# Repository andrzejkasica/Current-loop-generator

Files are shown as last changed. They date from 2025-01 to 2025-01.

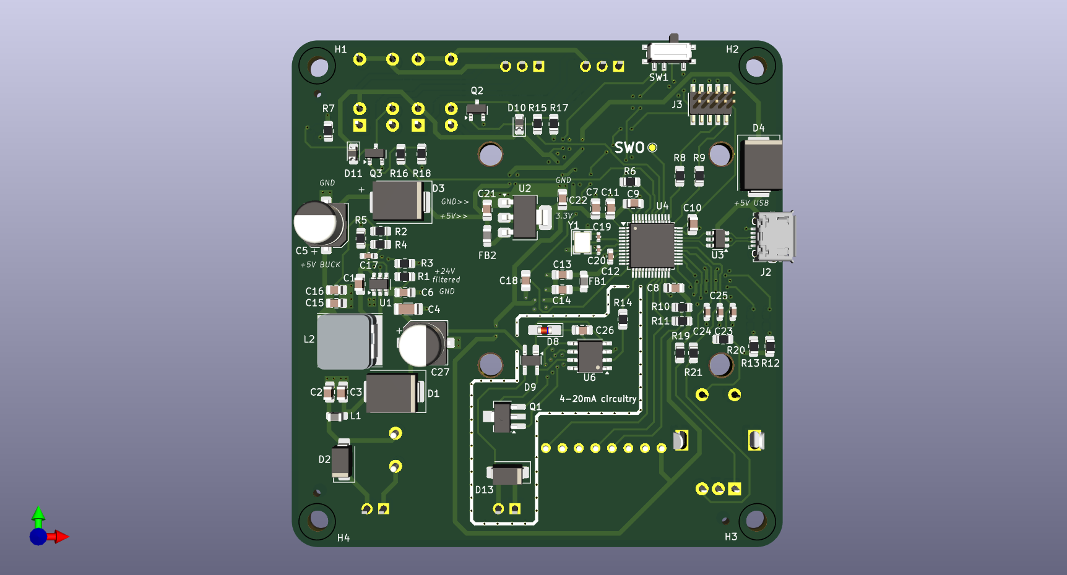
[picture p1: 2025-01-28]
Current_loop_gen-back.png

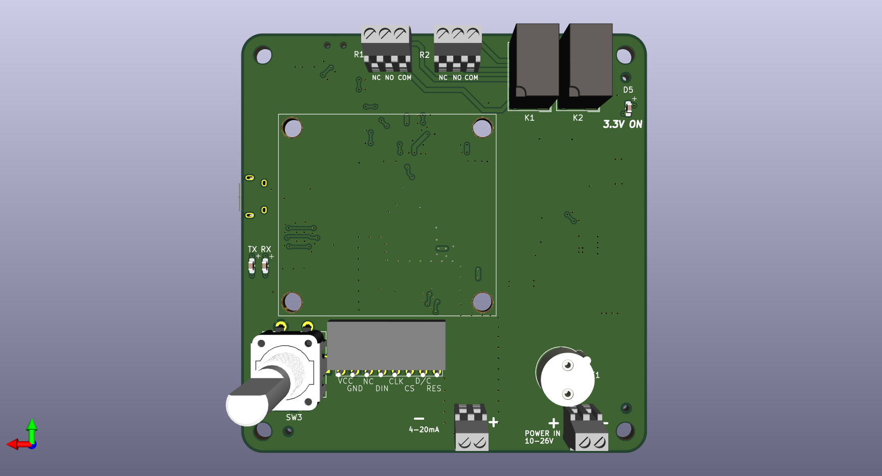
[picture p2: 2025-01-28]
Current_loop_gen-front.png

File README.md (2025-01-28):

# Current-loop-generator
Hardware project of 2-wire current loop generator with additonal 2 relays controlled by STM32L433CCT6 with OLED display and incremental encoder.
Powered with external 24V power supply, projects uses buck converter for +5V line and LDO for +3V3

PCB front: 
Current_loop_gen-front

Back of the PCB:
Current_loop_gen-back

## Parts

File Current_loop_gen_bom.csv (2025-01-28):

Reference | Value | Datasheet | Footprint | Qty | DNP | JLCPCB Part #
C12,C23,C24,C25 | 10n | ~ | -- różne wartości -- | 4 |  | C57112
C1,C2,C3,C6,C8,C9,C10,C11,C18,C26 | 100n | ~ | Capacitor_SMD:C_0805_2012Metric_Pad1.18x1.45mm_HandSolder | 10 |  | C49678
C15,C16,C21,C22 | 22u | ~ | Capacitor_SMD:C_0805_2012Metric_Pad1.18x1.45mm_HandSolder | 4 |  | C45783
C19,C20 | 10p | ~ | Capacitor_SMD:C_0402_1005Metric | 2 |  | C32949
C13,C14 | 1u | ~ | Capacitor_SMD:C_0805_2012Metric_Pad1.18x1.45mm_HandSolder | 2 |  | C28323
R4 | 100k | ~ | Resistor_SMD:R_0805_2012Metric_Pad1.20x1.40mm_HandSolder | 1 |  | C25741
R14 | 15k | ~ | Resistor_SMD:R_0805_2012Metric_Pad1.20x1.40mm_HandSolder | 1 |  | C17475
R17,R18 | 150k | ~ | Resistor_SMD:R_0805_2012Metric_Pad1.20x1.40mm_HandSolder | 2 |  | C17470
R19,R20,R21 | 10K | ~ | Resistor_SMD:R_0805_2012Metric_Pad1.20x1.40mm_HandSolder | 3 |  | C17414
R6 | 10k | ~ | Resistor_SMD:R_0805_2012Metric_Pad1.20x1.40mm_HandSolder | 1 |  | C17414
R8,R9 | 100 | ~ | Resistor_SMD:R_0805_2012Metric_Pad1.20x1.40mm_HandSolder | 2 |  | C17408
Y1 | 16MHz | ~ | Crystal:Crystal_SMD_3225-4Pin_3.2x2.5mm | 1 |  | C13738
U2 | AMS1117-3.3 | http://www.advanced-monolithic.com/pdf/ds1117.pdf | Package_TO_SOT_SMD:SOT-223-3_TabPin2 | 1 |  | C6186
FB1,L1 | 120R | ~ | Inductor_SMD:L_0805_2012Metric_Pad1.05x1.20mm_HandSolder | 2 |  | C5671
R7,R10,R11,R12,R13,R15,R16 | 1k5 | ~ | Resistor_SMD:R_0805_2012Metric_Pad1.20x1.40mm_HandSolder | 7 |  | C4310
C17 | 75p | ~ | Capacitor_SMD:C_0603_1608Metric_Pad1.08x0.95mm_HandSolder | 1 |  | C1671
FB2 | 100 @ 100MHz | ~ | Inductor_SMD:L_0805_2012Metric_Pad1.05x1.20mm_HandSolder | 1 |  | C1015

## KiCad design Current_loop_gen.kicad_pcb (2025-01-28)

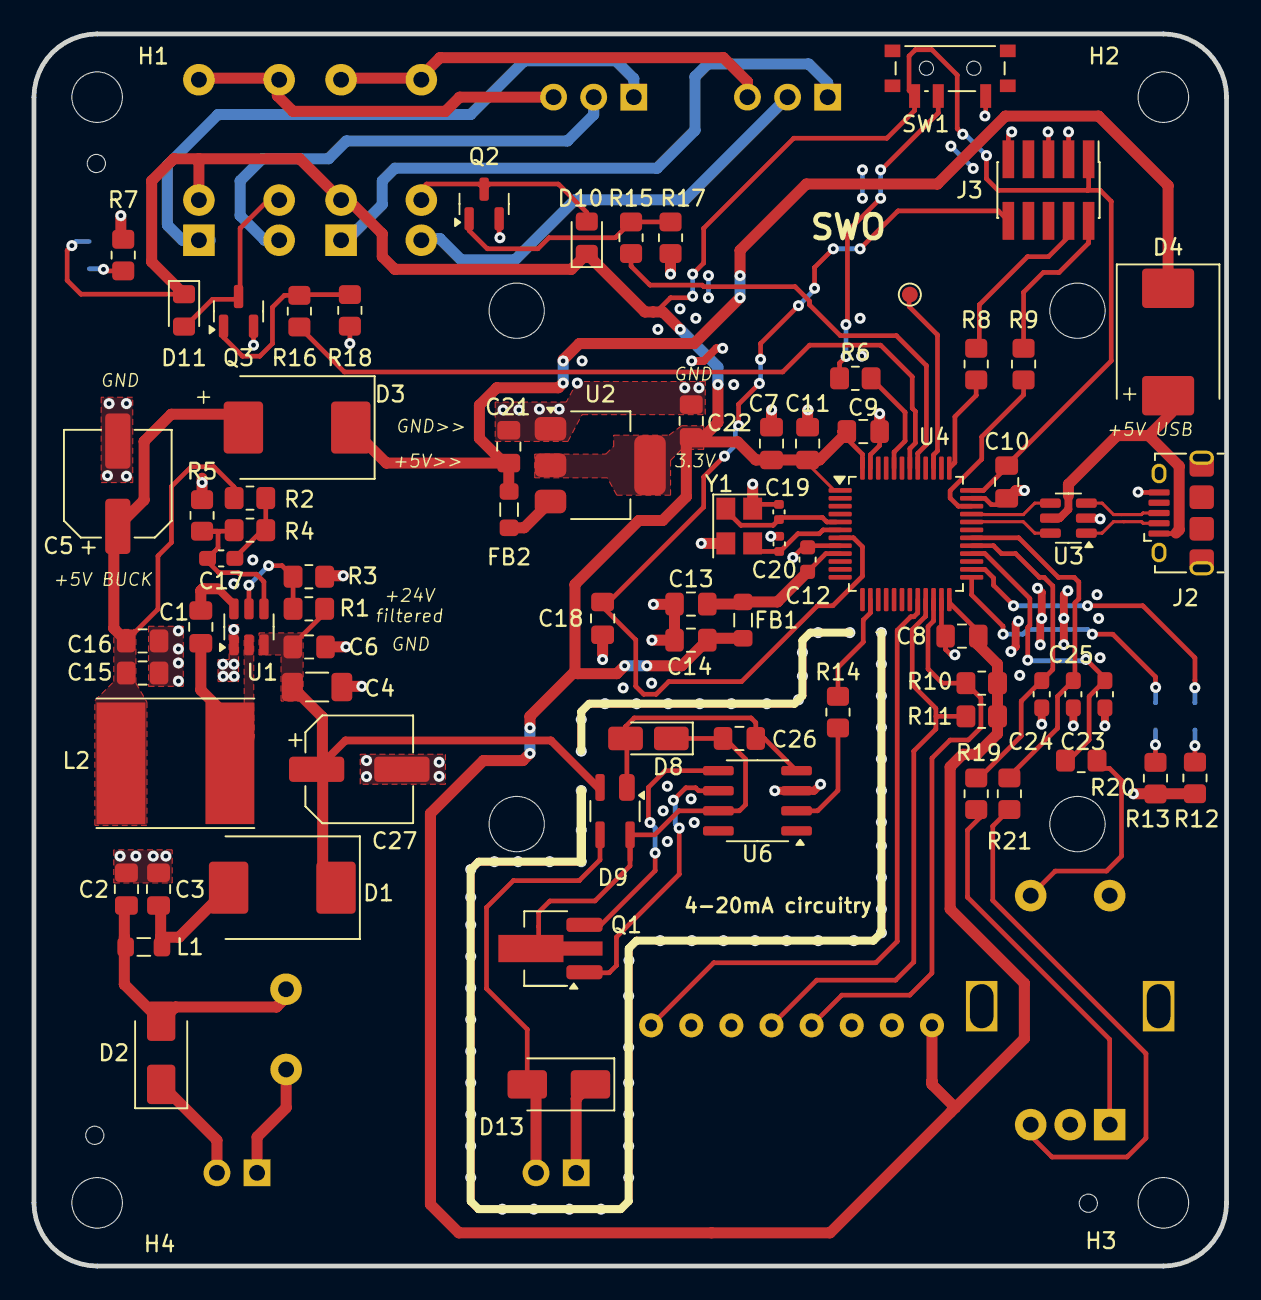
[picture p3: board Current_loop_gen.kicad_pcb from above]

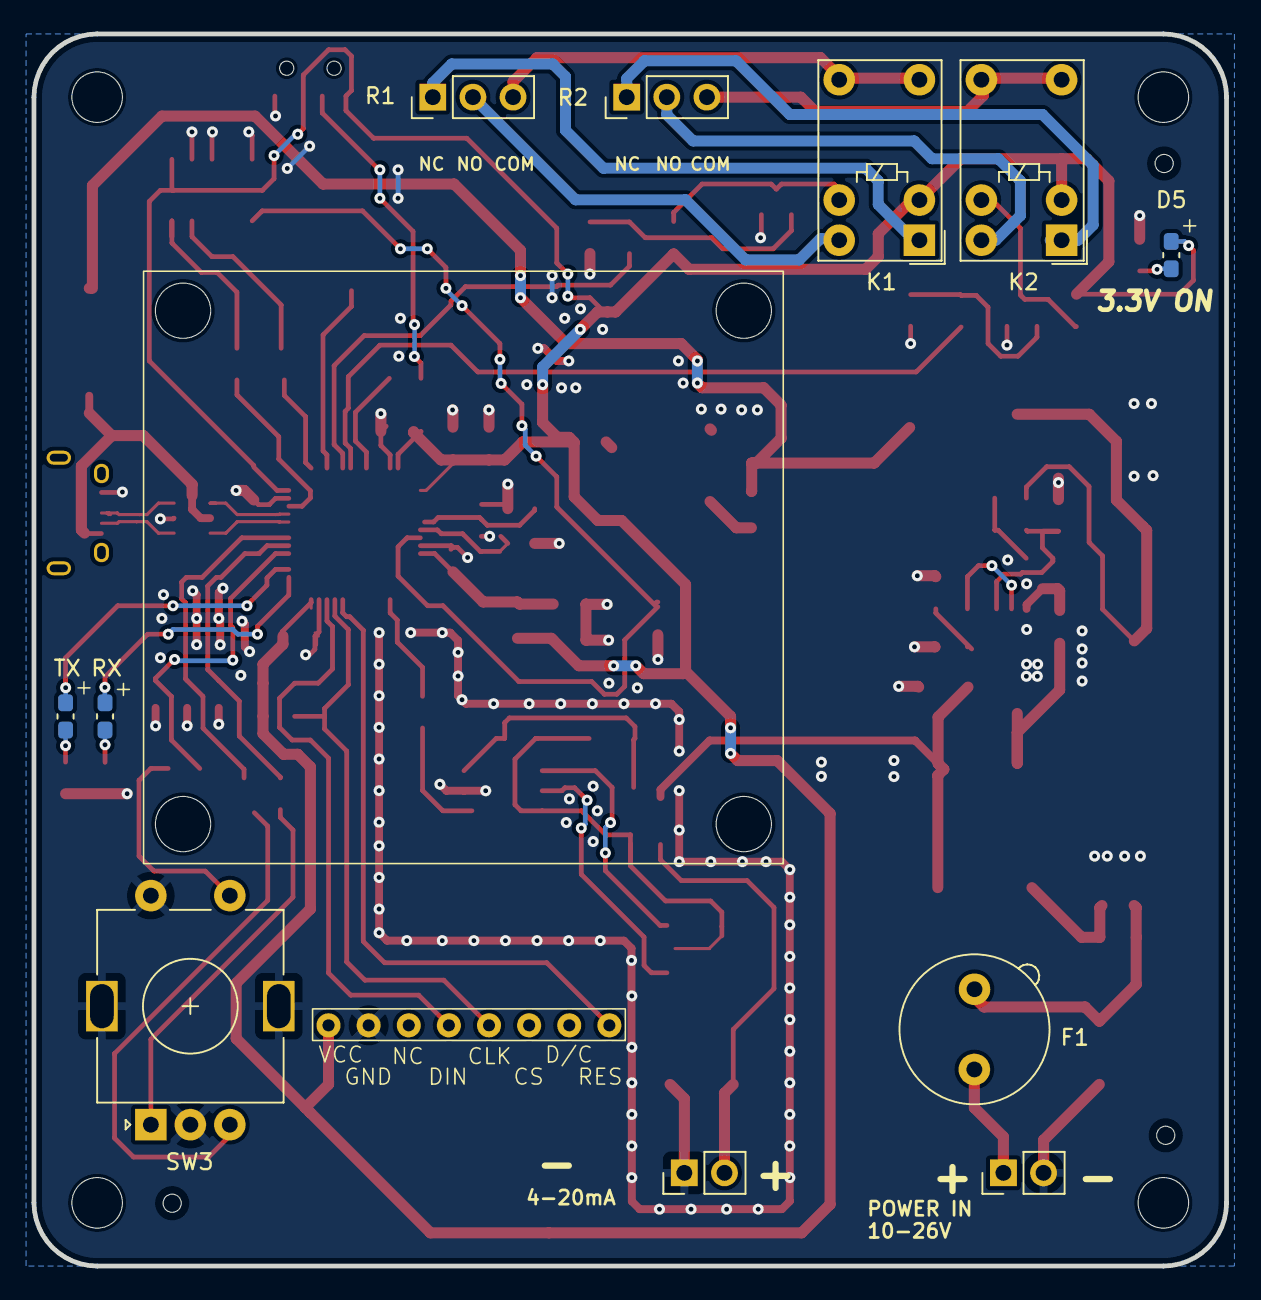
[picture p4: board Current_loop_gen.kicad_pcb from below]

Board: 2 copper layers, 75.5 x 78.0 mm, 90 parts (12 on the bottom side), 63 nets.

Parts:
C1, C2, C3, C6, C8, C9, C10, C11, C18, C26: 100n; C_0805_2012Metric_Pad1.18x1.45mm_HandSolder
C4: 22u; C_1206_3216Metric_Pad1.33x1.80mm_HandSolder
C5, C27: 47u; CP_Elec_6.3x5.8
C7: 10u; C_0805_2012Metric_Pad1.18x1.45mm_HandSolder
C12: 10n; C_0603_1608Metric
C13, C14: 1u; C_0805_2012Metric_Pad1.18x1.45mm_HandSolder
C15, C16, C21, C22: 22u; C_0805_2012Metric_Pad1.18x1.45mm_HandSolder
C17: 75p; C_0603_1608Metric_Pad1.08x0.95mm_HandSolder
C19, C20: 10p; C_0402_1005Metric
C23, C24, C25: 10n; C_0603_1608Metric_Pad1.08x0.95mm_HandSolder
D1: B340; D_SMC
D2, D13: SMAJ30CA; D_SMA
D3, D4: SX33L_R1; D_SMC
D5: RED; C_0603_1608Metric_Pad1.08x0.95mm_HandSolder
D6: BLUE; C_0603_1608Metric_Pad1.08x0.95mm_HandSolder
D7: GREEN; C_0603_1608Metric_Pad1.08x0.95mm_HandSolder
D8: 1N47xxA; D_MicroMELF_Handsoldering
D9: BAS4002ARPPE6327; SOT-143_Handsoldering
D10, D11: 1N4148; D_0805_2012Metric_Pad1.15x1.40mm_HandSolder
F1: Fuse_Small; Fuseholder_TR5_Littelfuse_No560_No460
FB1: 120R; L_0805_2012Metric_Pad1.05x1.20mm_HandSolder
FB2: 100 @ 100MHz; L_0805_2012Metric_Pad1.05x1.20mm_HandSolder
H1, H2, H3, H4: MountingHole; MountingHole_3.2mm_M3_DIN965
J1: Power 24V; PinHeader_1x02_P2.54mm_Vertical
J2: USB_B_Micro; USB_Micro-B_Amphenol_10118194-0001LF_Horizontal
J3: SWD Debug; PinHeader_2x05_P1.27mm_Vertical_SMD
J4: Current loop out; PinHeader_1x02_P2.54mm_Vertical
J5, J6: Conn_01x03; PinHeader_1x03_P2.54mm_Vertical
K1, K2: G5V-1; Relay_SPDT_Omron_G5V-1
L1: 120R; L_0805_2012Metric_Pad1.05x1.20mm_HandSolder
L2: 10u; L_Taiyo-Yuden_NR-80xx_HandSoldering
Q1: FCE690; SOT-89-3_Handsoldering
Q2, Q3: DMN65D8L-7; SOT-23
R1: 511k; R_0805_2012Metric_Pad1.20x1.40mm_HandSolder
R2: 49k9; R_0805_2012Metric_Pad1.20x1.40mm_HandSolder
R3: 105k; R_0805_2012Metric_Pad1.20x1.40mm_HandSolder
R4: 100k; R_0805_2012Metric_Pad1.20x1.40mm_HandSolder
R5: 13k3; R_0805_2012Metric_Pad1.20x1.40mm_HandSolder
R6: 10k; R_0805_2012Metric_Pad1.20x1.40mm_HandSolder
R7, R10, R11, R12, R13, R15, R16: 1k5; R_0805_2012Metric_Pad1.20x1.40mm_HandSolder
R8, R9: 100; R_0805_2012Metric_Pad1.20x1.40mm_HandSolder
R14: 15k; R_0805_2012Metric_Pad1.20x1.40mm_HandSolder
R17, R18: 150k; R_0805_2012Metric_Pad1.20x1.40mm_HandSolder
R19, R20, R21: 10K; R_0805_2012Metric_Pad1.20x1.40mm_HandSolder
SW1: SW_SPDT; SW_SPDT_PCM12
SW3: RotaryEncoder_Switch_MP; RotaryEncoder_Alps_EC11E-Switch_Vertical_H20mm
TP1: TestPoint; TestPoint_Pad_D1.0mm
U1: TPS54302; SOT-23-6
U2: AMS1117-3.3; SOT-223-3_TabPin2
U3: USBLC6-2SC6; SOT-23-6
U4: STM32L433CCTx; LQFP-48_7x7mm_P0.5mm
U5: WSH-10451; wsh-10451
U6: XTR116U; SOIC-8_3.9x4.9mm_P1.27mm
Y1: 16MHz; Crystal_SMD_3225-4Pin_3.2x2.5mm

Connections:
+3.3V: C7.1, C8.1, C9.1, C10.1, C11.1, C14.1, C22.1, D5.2 (A), D10.1 (K), D11.1 (K), FB1.2, J3.1, K1.2, K2.2, R10.1, R11.1, SW1.3 (C), U2.2 (VO), U4.1 (VBAT), U4.24 (VDD), U4.36 (VDDUSB), U4.48 (VDD), U5.8 (VCC)
+3.3VA: C12.1, C13.1, FB1.1, U4.9 (VDDA)
+5VTPS: C5.1, C15.1, C16.1, D3.2 (A), L2.2, R2.1
+24V: C4.1, C6.1, C27.1, D1.1 (K), D9.2, R1.1, U1.3 (VIN)
/ALARM1: R15.1, U4.41 (PB5)
/ALARM2: R16.1, U4.42 (PB6)
/BOOT0: R6.2, U4.44 (PH3)
/Buck_BOOT: C1.1, U1.6 (BOOT)
/Buck_EN: R1.2, R3.1, U1.5 (EN)
/Buck_FB: C17.2, R4.2, R5.1, U1.4 (FB)
/Buck_SW: C1.2, L2.1, U1.2 (SW)
/DAC1_OUT1: R14.1, U4.14 (PA4)
/DAC1_XTR_IN: R14.2, U6.2 (IIN)
/HSE_IN: C19.1, U4.5 (PH0), Y1.1
/HSE_OUT: C20.1, U4.6 (PH1), Y1.3
/I2C2_SCL: R11.2, U4.21 (PB10), U5.4 (CLK)
/I2C2_SDA: R10.2, U4.22 (PB11), U5.5 (DIN)
/LED_BLUE: D6.2 (A), U4.26 (PB13)
/LED_GREEN: D7.2 (A), U4.25 (PB12)
/NRST: C18.1, J3.10, U4.7 (NRST)
/PWR_LED_K: D5.1 (K), R7.1
/R1_COM: J5.3, K1.5, K1.6
/R1_NC: J5.1, K1.1
/R1_NO: J5.2, K1.10
/R2_COM: J6.3, K2.5, K2.6
/R2_NC: J6.1, K2.1
/R2_NO: J6.2, K2.10
/RE_S_A: C24.1, R19.1, U4.29 (PA8)
/RE_S_B: C25.1, R21.1, U4.30 (PA9)
/RE_S_SW: C23.1, R20.2, U4.28 (PB15)
/SWCLK: R8.2, U4.37 (PA14)
/SWDIO: R9.1, U4.34 (PA13)
/SWO: TP1.1, U4.39 (PB3)
/USB_CONN_DP+: J2.3 (D+), U3.3 (I/O2)
/USB_CONN_DP-: J2.2 (D-), U3.1 (I/O1)
/USB_DP+: U3.4 (I/O2), U4.33 (PA12)
/USB_DP-: U3.6 (I/O1), U4.32 (PA11)
/WSH_RST: U4.20 (PB2), U5.1 (RES)
/XTR_IO: C26.2, D8.2 (A), D9.1 (-), U6.4 (IO)
/XTR_VPLUS: C26.1, D8.1 (K), D9.4 (+), Q1.2 (C), U6.7 (V+)
GND: C2.2, C3.2, C4.2, C5.2, C6.2, C7.2, C8.2, C9.2, C10.2, C11.2, C12.2, C13.2, C14.2, C15.2, C16.2, C18.2, C19.2, C20.2, C21.2, C22.2, C23.2, C24.2, C25.2, C27.2, D2.1 (A1), D13.1 (A1), J1.2, J2.5 (GND), J3.3, J3.5, J3.9, J4.1, Q2.2 (S), Q3.2 (S), R3.2, R5.2, R7.2, R12.2, R13.2, R17.1, R18.1, SW1.1 (A), SW3.C, SW3.MP, SW3.S2, U1.1 (GND), U2.1 (GND), U3.2 (GND), U4.8 (VSSA), U4.23 (VSS), U4.35 (VSS), U4.47 (VSS), U5.7 (GND), U6.3 (IRET), Y1.2, Y1.4
unnamed: C17.1, R2.2, R4.1
unnamed: C3.1, D1.2 (A), L1.2
unnamed: C2.1, D2.2 (A2), F1.2, L1.1
unnamed: D6.1 (K), R12.1
unnamed: D7.1 (K), R13.1
unnamed: D10.2 (A), K1.9, Q2.3 (D)
unnamed: D11.2 (A), K2.9, Q3.3 (D)
unnamed: D9.3, D13.2 (A2), J4.2
unnamed: J3.2, R9.2
unnamed: J3.4, R8.1
unnamed: Q1.1 (B), U6.6 (B)
unnamed: Q1.3 (E), U6.5 (E)
unnamed: Q2.1 (G), R15.2, R17.2
unnamed: Q3.1 (G), R16.2, R18.2
unnamed: R19.2, SW3.A
unnamed: R20.1, SW3.S1
unnamed: R21.2, SW3.B
unnamed: R6.1, SW1.2 (B)
unnamed: FB2.2, U2.3 (VI)
VBUS: C21.1, D3.1 (K), D4.1 (K), FB2.1
VBUS_USB: D4.2 (A), J2.1 (VBUS), U3.5 (VBUS)
VDC: F1.1, J1.1

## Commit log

2025-01-28 Commiting hardware project
    [Current_loop_gen.kicad_pcb, Current_loop_gen.kicad_sch]
2025-01-28 Production files
    Manufacturing and assembly files for JLCPCB, some parts were assembly separately
    [Current_loop_gen_bom.csv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]
